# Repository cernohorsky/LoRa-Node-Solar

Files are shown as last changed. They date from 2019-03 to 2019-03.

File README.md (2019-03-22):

# LoRa Node

It uses the MCP73871 - USB/Solar panel charger and very nice TPS63031 Buck-Boost Converter. Main benefits of the board is small size and possibility to run literally forever from one small single cell LiPo battery.

It's necessary to <b>burn bootloader with ISP before RFM95W module is soldered</b>.

<b>ToDo:</b><br>
Change ground symbols<br>
Create BOM<br>

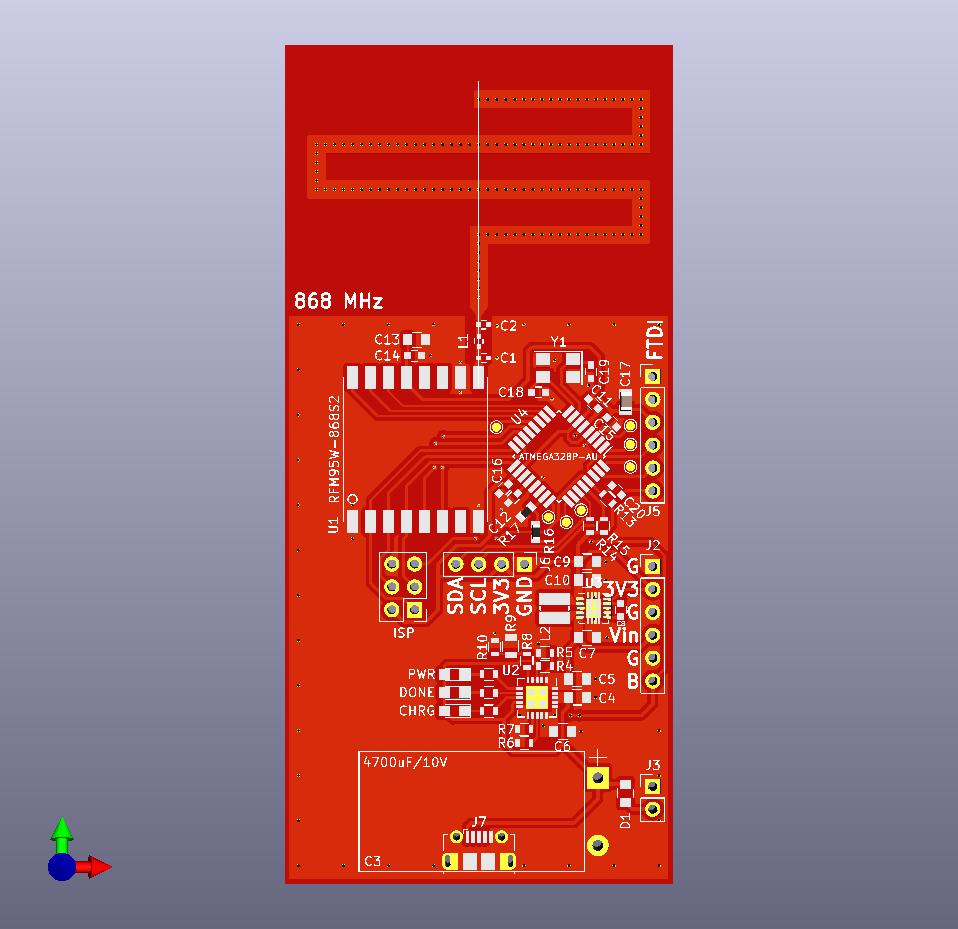
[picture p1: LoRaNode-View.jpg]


#RFM95W, #ATMEGA328P,  #TPS63031, #MCP7381, #Arduino

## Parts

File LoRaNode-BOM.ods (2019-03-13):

 |  | ks | cena/ks | cena
ATMEGA328P-AU | http://de.farnell.com/microchip/atmega328p-au/mcu-8bit-avr-32k-flash-32tqfp/dp/1715486?st=atmega328p | 5 | 1,86 | 9,3
TPS63031 | http://de.farnell.com/texas-instruments/tps63031dskt/abw-rts-aufw-rts-wandler-0-9a/dp/2437733?st=TPS63031DSKT | 5 | 2,06 | 10,3
TMCP73871 | http://de.farnell.com/microchip/mcp73871-2cci-ml/batterie-management-cont-qfn20/dp/1642489?st=MCP73871 | 5 | 1,8 | 9
MBR120VLS | http://de.farnell.com/on-semiconductor/mbr120vlsft1g/schottky-diode-1a-20v-sod-123fl/dp/1431044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 | 5 | 0,344 | 1,72
4700u/10V | http://de.farnell.com/panasonic-electronic-components/eca1ahg472/alu-elko-4700uf-10v-radial/dp/9692754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 | 5 | 1,29 | 6,45
microUSB | http://de.farnell.com/molex/105017-0001/micro-usb-2-0-buchse-typ-b-smd/dp/2293836?st=molex%20105017 | 10 | 0,547 | 5,47
NTC 10k | http://de.farnell.com/murata/ncp21xv103j03ra/thermistor-ntc-10k-5-0805/dp/2456126?st=ntc | 10 | 0,137 | 1,37
2p7 | GRM1555C1H2R7CZ01D
1n8 | LQG15HS1N8S02D

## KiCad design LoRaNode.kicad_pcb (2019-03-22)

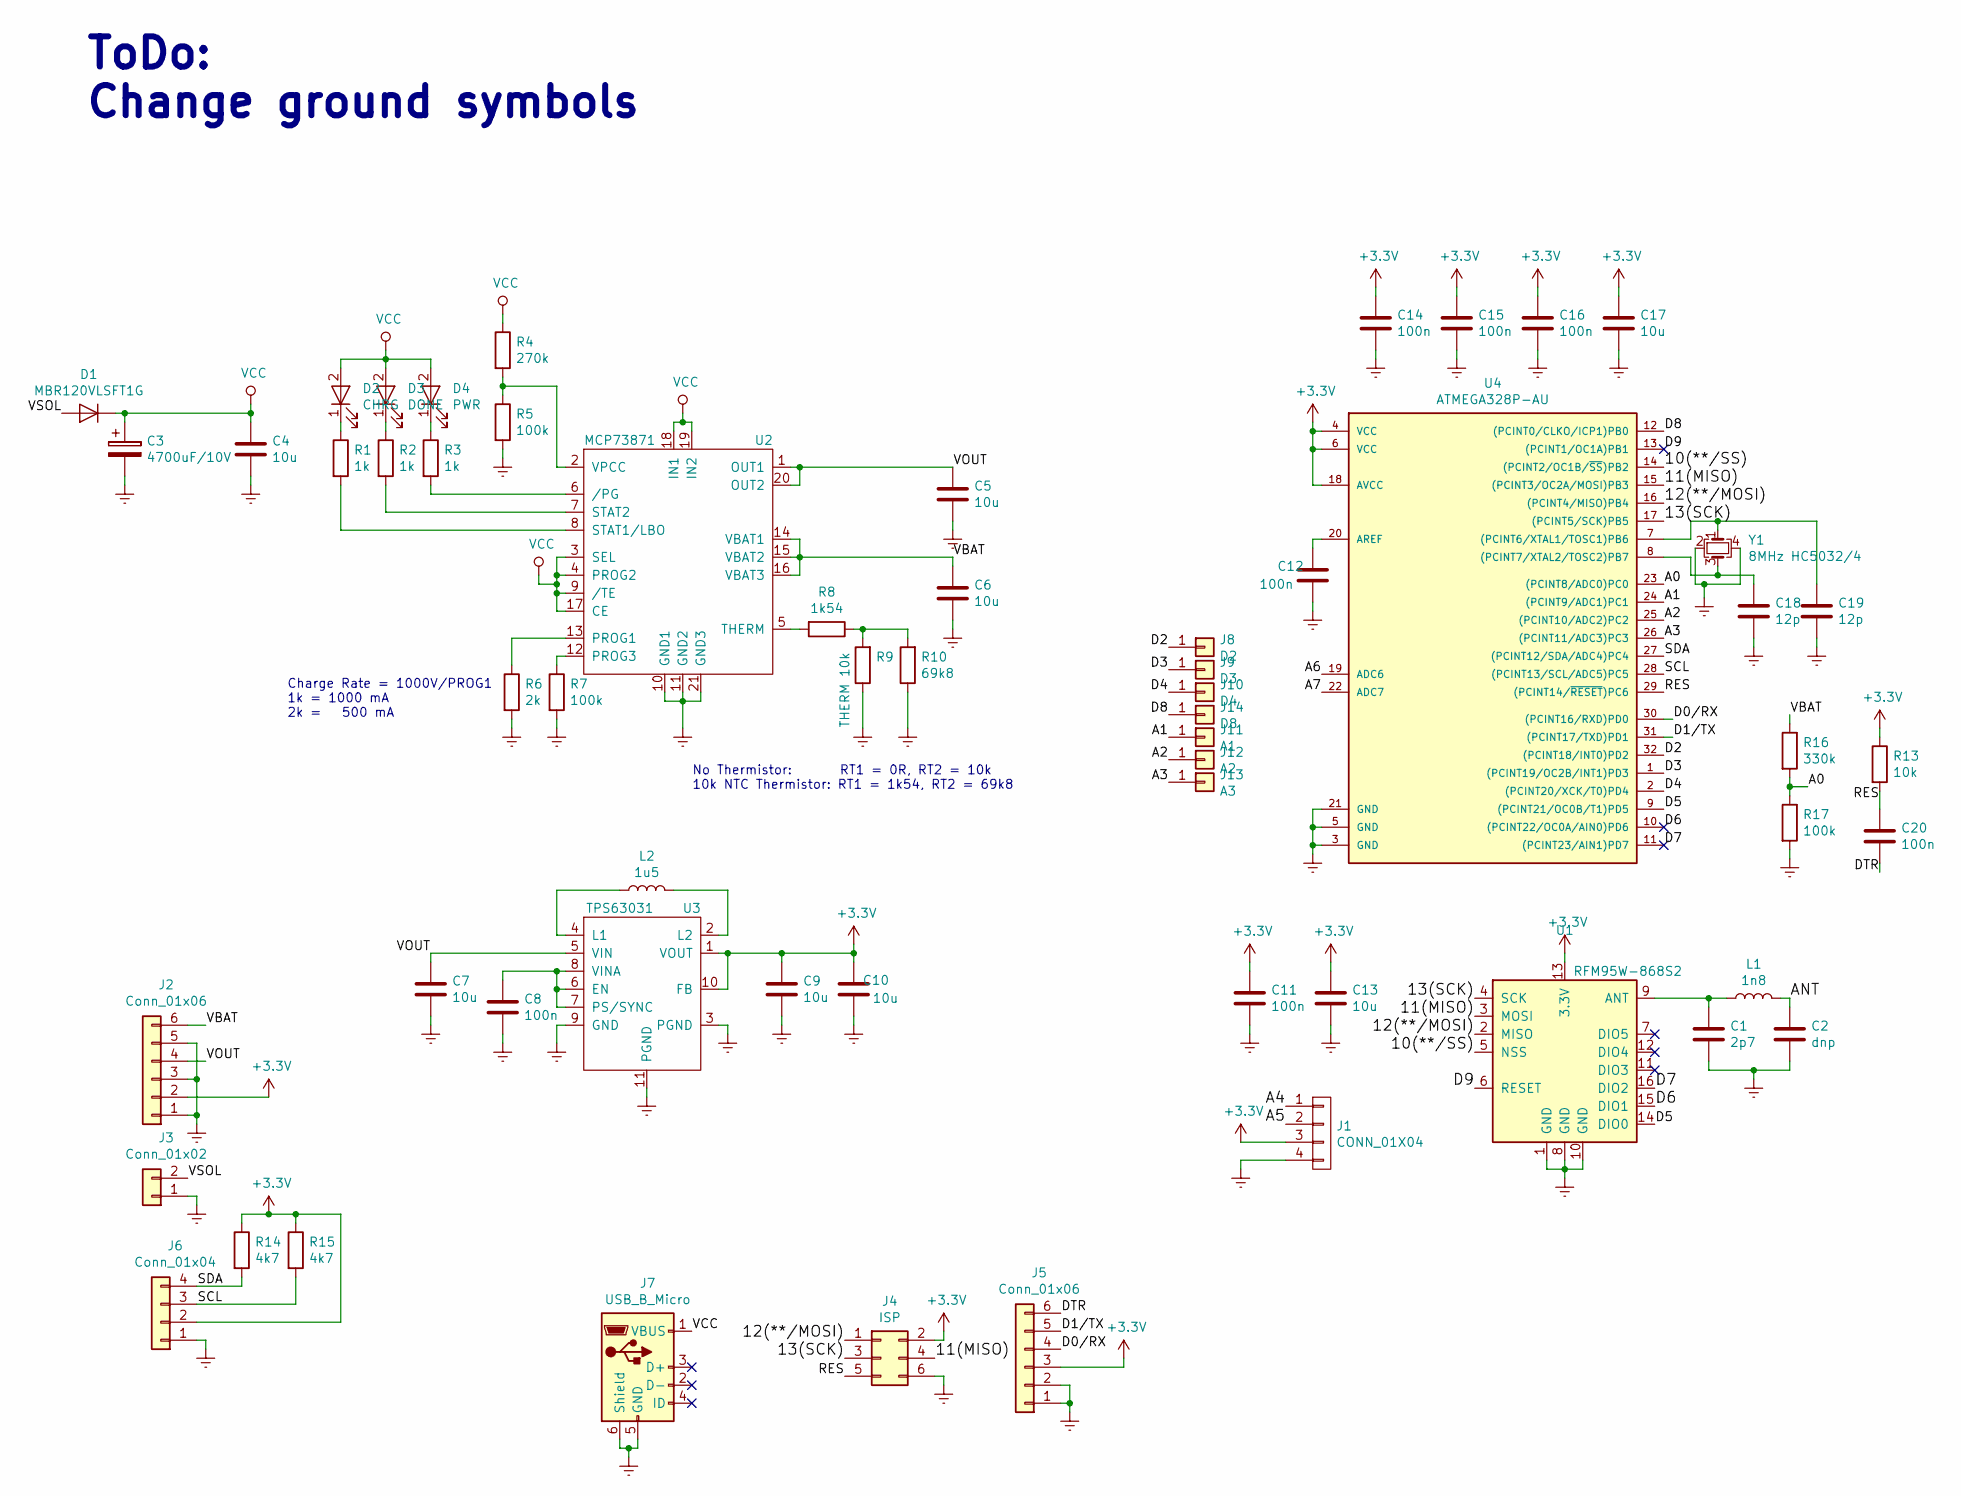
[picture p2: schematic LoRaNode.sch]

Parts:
C1: 2p7; C_0402
C2: dnp; C_0402
C3: 4700uF/10V; CP_Radial_D12.5mm_P25mm
C4, C5, C6, C7, C9, C10, C13: 10u; C_0805
C8, C11, C12, C14, C15, C16, C20: 100n; C_0603
C17: 10u; C_0805_2012Metric
C18, C19: 12p; C_0603
D1: MBR120VLSFT1G; C_0805
D2: CHRG; LED_0805
D3: DONE; LED_0805
D4: PWR; LED_0805
J1: CONN_01X04; RJ12GLP-AMP(RJ12)
J2, J5: Conn_01x06; Pin_Header_Straight_1x06_Pitch2.54mm
J3: Conn_01x02; Pin_Header_Straight_1x02_Pitch2.54mm
J4: ISP; Pin_Header_Straight_2x03_Pitch2.54mm
J6: Conn_01x04; Pin_Header_Straight_1x04_Pitch2.54mm
J7: USB_B_Micro; USB_Micro-B_Molex-105017-0001
J8: D2; TestPoint_Pad_D1.0mm
J9: D3; TestPoint_Pad_D1.0mm
J10: D4; TestPoint_Pad_D1.0mm
J11: A1; TestPoint_Pad_D1.0mm
J12: A2; TestPoint_Pad_D1.0mm
J13: A3; TestPoint_Pad_D1.0mm
J14: D8; TestPoint_Pad_D1.0mm
L1: 1n8; C_0402
L2: 1u5; Inductor_Wurth_MAPI-3012
R1, R2, R3: 1k; R_0603
R4: 270k; R_0603
R5, R7: 100k; R_0603
R6: 2k; R_0603
R8: 1k54; R_0603
R9: THERM 10k; R_0805
R10: 69k8; R_0603
R13: 10k; R_0603
R14, R15: 4k7; R_0603
R16: 330k; R_0603_1608Metric
R17: 100k; R_0603_1608Metric
U1: RFM95W-868S2; RFM95W
U2: MCP73871; QFN-20-1EP_4x4mm_Pitch0.5mm
U3: TPS63031; Texas_S-PWSON-N10
U4: ATMEGA328P-AU; TQFP-32_7x7mm_Pitch0.8mm
Y1: 8MHz HC5032/4; Crystal_SMD_5032-4pin_5.0x3.2mm

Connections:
+3V3: C9.1, C10.2, C11.1, C13.1, C14.1, C15.1, C16.1, C17.1, J1.3, J2.2, J4.2, J5.3, J6.2, R13.1, R14.1, R15.1, U1.13 (3.3V), U3.1 (VOUT), U3.10 (FB), U4.4 (VCC), U4.6 (VCC), U4.18 (AVCC)
/10(**/SS): U1.5 (NSS), U4.14 ((PCINT2/OC1B/~SS~)PB2)
/11(MISO): J4.4, U1.3 (MOSI), U4.15 ((PCINT3/OC2A/MOSI)PB3)
/12(**/MOSI): J4.1, U1.2 (MISO), U4.16 ((PCINT4/MISO)PB4)
/13(SCK): J4.3, U1.4 (SCK), U4.17 ((PCINT5/SCK)PB5)
/A0: R16.2, R17.1, U4.23 ((PCINT8/ADC0)PC0)
/A1: J11.1, U4.24 ((PCINT9/ADC1)PC1)
/A2: J12.1, U4.25 ((PCINT10/ADC2)PC2)
/A3: J13.1, U4.26 ((PCINT11/ADC3)PC3)
/ANT: C2.1, L1.2
/D0/RX: J5.4, U4.30 ((PCINT16/RXD)PD0)
/D1/TX: J5.5, U4.31 ((PCINT17/TXD)PD1)
/D2: J8.1, U4.32 ((PCINT18/INT0)PD2)
/D3: J9.1, U4.1 ((PCINT19/OC2B/INT1)PD3)
/D4: J10.1, U4.2 ((PCINT20/XCK/T0)PD4)
/D5: U1.14 (DIO0), U4.9 ((PCINT21/OC0B/T1)PD5)
/D6: U1.15 (DIO1), U4.10 ((PCINT22/OC0A/AIN0)PD6)
/D7: U1.16 (DIO2), U4.11 ((PCINT23/AIN1)PD7)
/D8: J14.1, U4.12 ((PCINT0/CLKO/ICP1)PB0)
/D9: U1.6 (RESET), U4.13 ((PCINT1/OC1A)PB1)
/DTR: C20.2, J5.6
/RES: C20.1, J4.5, R13.2, U4.29 ((PCINT14/~RESET~)PC6)
/SCL: J6.3, R15.2, U4.28 ((PCINT13/SCL/ADC5)PC5)
/SDA: J6.4, R14.2, U4.27 ((PCINT12/SDA/ADC4)PC4)
/VBAT: C6.1, J2.6, R16.1, U2.14 (VBAT1), U2.15 (VBAT2), U2.16 (VBAT3)
/VOUT: C5.1, C7.1, J2.4, U2.1 (OUT1), U2.20 (OUT2), U3.5 (VIN)
/VSOL: D1.2 (A), J3.2
Earth: C1.2, C2.2, C3.2, C4.2, C5.2, C6.2, C7.2, C8.2, C9.2, C10.1, C11.2, C12.2, C13.2, C14.2, C15.2, C16.2, C17.2, C18.2, C19.2, J1.4, J2.1, J2.3, J2.5, J3.1, J4.6, J5.1, J5.2, J6.1, J7.5 (GND), J7.6 (Shield), R5.2, R6.2, R7.2, R9.1, R10.1, R17.2, U1.1 (GND), U1.8 (GND), U1.10 (GND), U2.10 (GND1), U2.11 (GND2), U2.21 (GND3), U3.3 (PGND), U3.9 (GND), U3.11 (PGND), U4.3 (GND), U4.5 (GND), U4.21 (GND), Y1.2, Y1.4
unnamed: C1.1, L1.1, U1.9 (ANT)
unnamed: C8.1, U3.6 (EN), U3.7 (PS/SYNC), U3.8 (VINA)
unnamed: C12.1, U4.20 (AREF)
unnamed: C18.1, U4.8 ((PCINT7/XTAL2/TOSC2)PB7), Y1.3
unnamed: C19.1, U4.7 ((PCINT6/XTAL1/TOSC1)PB6), Y1.1
unnamed: D2.1 (K), R1.1
unnamed: D3.1 (K), R2.1
unnamed: D4.1 (K), R3.1
unnamed: L2.1, U3.4 (L1)
unnamed: L2.2, U3.2 (L2)
unnamed: R1.2, U2.8 (STAT1/LBO)
unnamed: R2.2, U2.7 (STAT2)
unnamed: R3.2, U2.6 (/PG)
unnamed: R4.2, R5.1, U2.2 (VPCC)
unnamed: R6.1, U2.13 (PROG1)
unnamed: R7.1, U2.12 (PROG3)
unnamed: R8.2, U2.5 (THERM)
unnamed: R8.1, R9.2, R10.2
VCC: C3.1, C4.1, D1.1 (K), D2.2 (A), D3.2 (A), D4.2 (A), J7.1 (VBUS), R4.1, U2.3 (SEL), U2.4 (PROG2), U2.9 (/TE), U2.17 (CE), U2.18 (IN1), U2.19 (IN2)

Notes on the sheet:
Charge Rate = 1000V/PROG1 1k = 1000 mA 2k = 500 mA
No Thermistor: RT1 = 0R, RT2 = 10k 10k NTC Thermistor: RT1 = 1k54, RT2 = 69k8
ToDo: Change ground symbols

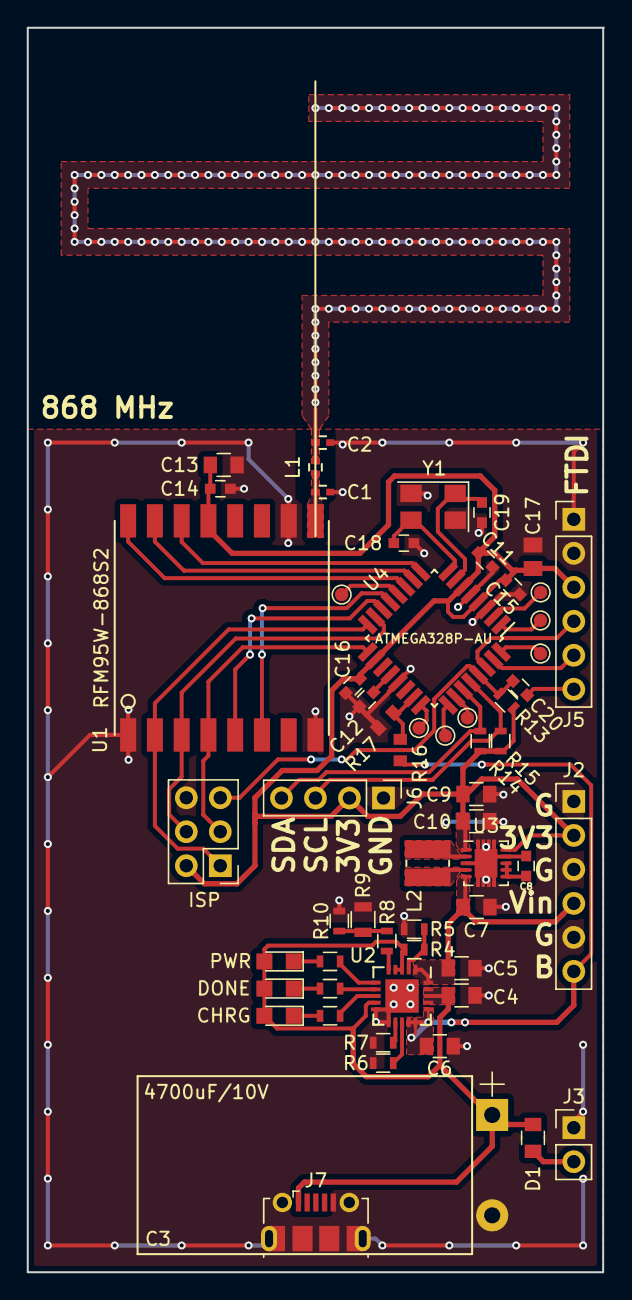
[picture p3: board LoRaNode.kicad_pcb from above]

Board: 2 copper layers, 43.0 x 93.0 mm, 59 parts (0 on the bottom side), 47 nets.

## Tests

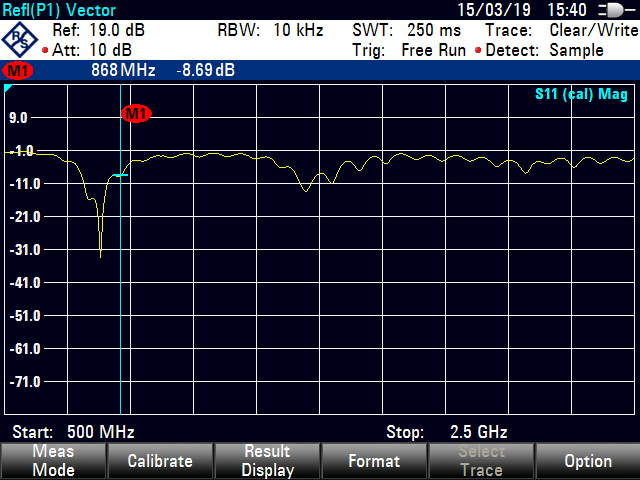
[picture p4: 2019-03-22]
AntennaMeasurement-S11.png

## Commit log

2019-03-13 SPI bugfix, FTDI reset bugfix, GPIO pads addition
    [Arduino_Mini.kicad_pcb, Arduino_Mini.sch, _saved_Arduino_Mini.sch]
2019-03-13 Changed Antenna dimension, changed TPS63031 footprint
    [LoRaNode.kicad_pcb, LoRaNode.sch, _saved_Arduino_Mini.sch]
2019-03-22 Added antenna measurement result, added actual pcb image
    [LoRaNode.kicad_pcb]
